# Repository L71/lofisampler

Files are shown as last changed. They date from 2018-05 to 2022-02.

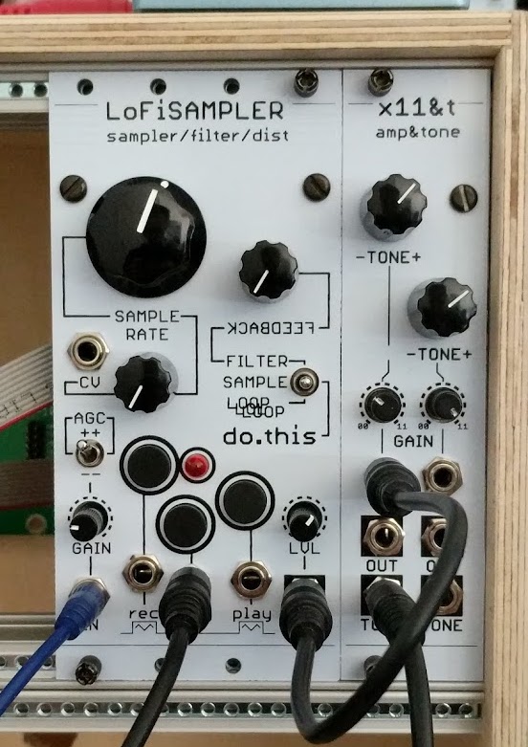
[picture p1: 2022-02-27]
lofisampler_tonecontrol.jpeg

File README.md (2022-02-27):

LoFi sampler / filter / dist module
===================================

This is a Eurorack module built upon the circuits described here: 

http://www.bastl-instruments.com/instruments/omsynth/omsynthvideo3/
http://www.bastl-instruments.com/instruments/omsynth/omsynthvideo3/lo-fi-vcf/

The added stuff here is Eurorack power supply circuits, an output amplifier and
some circuitry to get correct polarity on the sample rate/filter bandwidth control voltage.

It does sample and play stuff back but it's _really_ lofi as a sampler, lots of clicks at
start and stop of playback. It works better as a lofi filter or dist.

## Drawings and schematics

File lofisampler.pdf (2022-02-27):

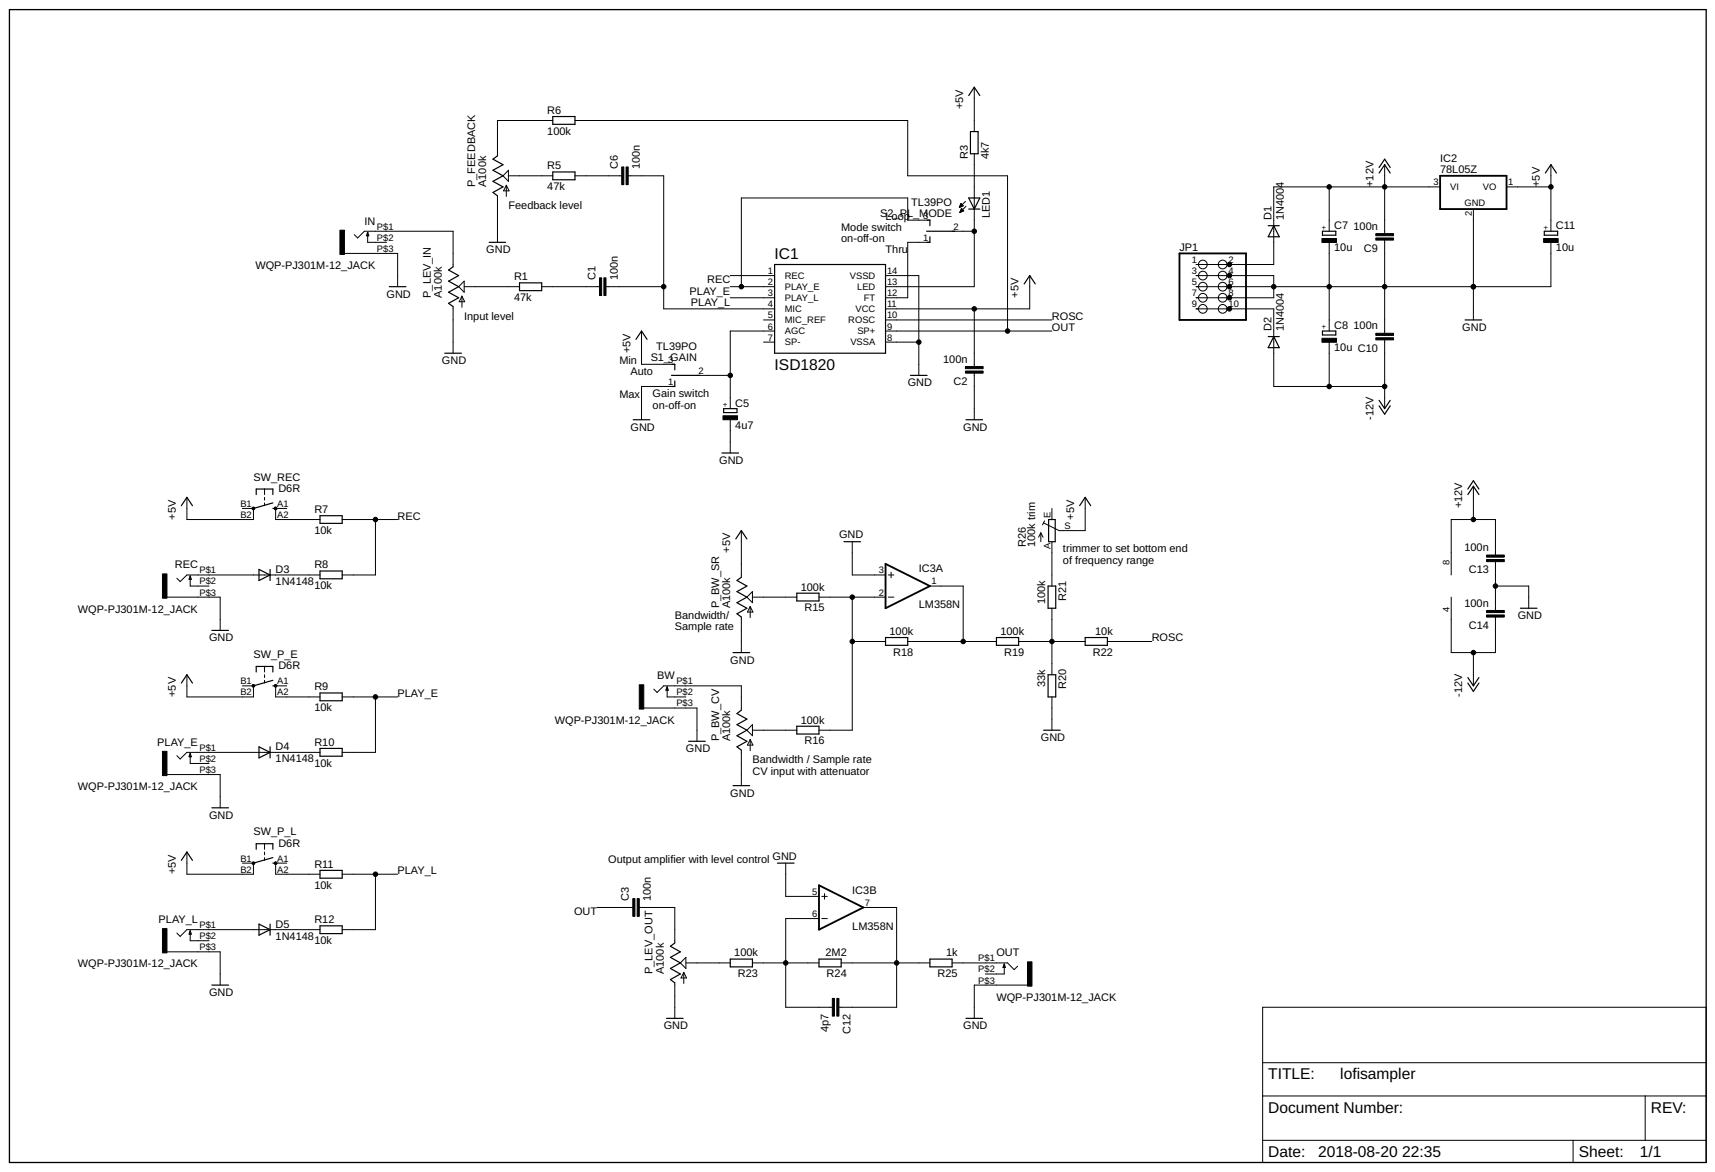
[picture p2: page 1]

trimmer to set bottom end
of frequency range

Bandwidth / Sample rate CV input with attenuator Output amplifier with level control

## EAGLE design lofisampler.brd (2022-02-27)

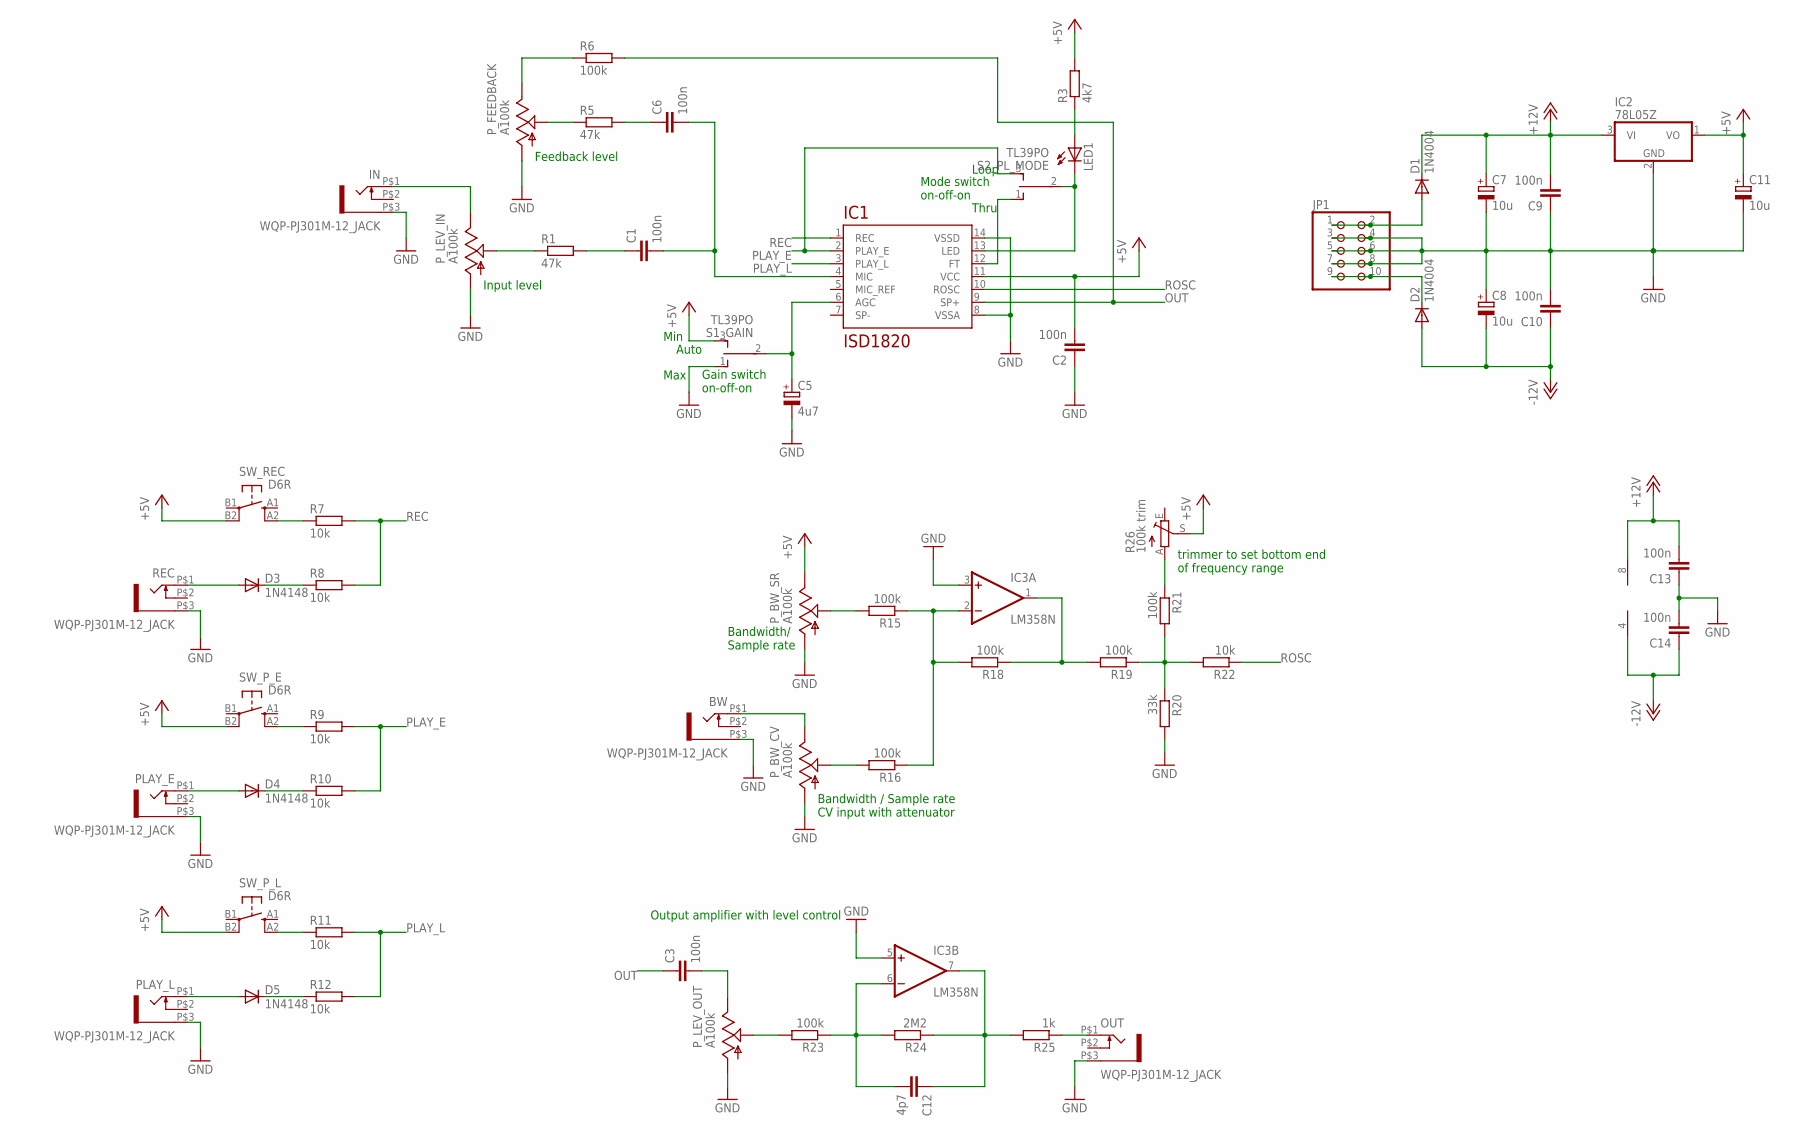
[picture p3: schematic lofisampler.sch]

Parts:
BW: WQP-PJ301M-12_JACK
C1, C3, C6: 100n; C050-025X075
C2, C9, C10, C13, C14: 100n; C025-025X050
C5: 4u7; E2,5-5
C7, C8, C11: 10u; E2,5-5
C12: 4p7; C025-025X050
D1, D2: 1N4004; DO41-10
D3, D4, D5: 1N4148; DO35-7
IC1: ISD1820; DIL14
IC2: 78L05Z; TO92
IC3: LM358N; DIL08
IN: WQP-PJ301M-12_JACK
JP1: PINHD-2X5; 2X05
LED1: LED5MM
OUT: WQP-PJ301M-12_JACK
PLAY_E: WQP-PJ301M-12_JACK
PLAY_L: WQP-PJ301M-12_JACK
P_BW_CV: A100k; ALPS_POT_VERTICAL
P_BW_SR: A100k; ALPS_POT_VERTICAL
P_FEEDBACK: A100k; ALPS_POT_VERTICAL
P_LEV_IN: A100k; ALPS_POT_VERTICAL
P_LEV_OUT: A100k; ALPS_POT_VERTICAL
R1, R5: 47k; 0207/2V
R3: 4k7; 0207/2V
R6, R15, R16, R18, R19, R21, R23: 100k; 0207/2V
R7, R8, R9, R10, R11, R12, R22: 10k; 0207/2V
R20: 33k; 0207/2V
R24: 2M2; 0207/2V
R25: 1k; 0207/2V
R26: 100k trim; B25P
REC: WQP-PJ301M-12_JACK
S1_GAIN, S2_PL_MODE: TL39PO; TL3XPO
SW_P_E: D6R
SW_P_L: D6R
SW_REC: D6R

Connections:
+5V: C2.2, C11.+, IC1.11 (VCC), IC2.1 (VO), P_BW_SR.P$1 (E), R3.2, R26.S, S1_GAIN.3 (S), SW_P_E.B2 (P1), SW_P_L.B2 (P1), SW_REC.B2 (P1)
+12V: C7.+, C9.2, C13.2, D1.C, IC2.3 (VI), IC3.8 (V+)
-12V: C8.-, C10.1, C14.1, D2.A, IC3.4 (V-)
GND: BW.P$3 (1), C2.1, C5.-, C7.-, C8.+, C9.1, C10.2, C11.-, C13.1, C14.2, IC1.8 (VSSA), IC1.14 (VSSD), IC2.2 (GND), IC3.3 (+IN), IC3.5 (+IN), IN.P$3 (1), JP1.3, JP1.4, JP1.5, JP1.6, JP1.7, JP1.8, OUT.P$3 (1), PLAY_E.P$3 (1), PLAY_L.P$3 (1), P_BW_CV.P$3 (A), P_BW_SR.P$3 (A), P_FEEDBACK.P$3 (A), P_LEV_IN.P$3 (A), P_LEV_OUT.P$3 (A), R20.2, REC.P$3 (1), S1_GAIN.1 (O)
unnamed: IN.P$1 (2), P_LEV_IN.P$1 (E)
unnamed: P_LEV_IN.P$2 (S), R1.1
unnamed: C1.1, R1.2
unnamed: C1.2, C6.2, IC1.4 (MIC)
unnamed: LED1.A, R3.1
unnamed: IC1.13 (LED), LED1.K (C), S2_PL_MODE.2
unnamed: IC1.12 (FT), S2_PL_MODE.1 (O)
unnamed: P_FEEDBACK.P$1 (E), R6.1
unnamed: D1.A, JP1.1, JP1.2
unnamed: P_FEEDBACK.P$2 (S), R5.1
unnamed: C5.+, IC1.6 (AGC), S1_GAIN.2
unnamed: C6.1, R5.2
unnamed: D2.C, JP1.9, JP1.10
unnamed: R21.1, R26.A
unnamed: C3.2, P_LEV_OUT.P$1 (E)
unnamed: P_LEV_OUT.P$2 (S), R23.2
unnamed: C12.2, IC3.6 (-IN), R23.1, R24.2
unnamed: D3.A, REC.P$1 (2)
unnamed: D3.C, R8.1
unnamed: P_BW_SR.P$2 (S), R15.2
unnamed: R7.1, SW_REC.A2 (S1)
unnamed: P_BW_CV.P$2 (S), R16.2
unnamed: D4.A, PLAY_E.P$1 (2)
unnamed: D4.C, R10.1
unnamed: IC3.2 (-IN), R15.1, R16.1, R18.2
unnamed: R9.1, SW_P_E.A2 (S1)
unnamed: D5.A, PLAY_L.P$1 (2)
unnamed: D5.C, R12.1
unnamed: C12.1, IC3.7 (OUT), R24.1, R25.2
unnamed: R11.1, SW_P_L.A2 (S1)
unnamed: IC3.1 (OUT), R18.1, R19.2
unnamed: BW.P$1 (2), P_BW_CV.P$1 (E)
unnamed: R19.1, R20.1, R21.2, R22.2
unnamed: OUT.P$1 (2), R25.1
OUT: C3.1, IC1.9 (SP+), R6.2
PLAY_E: IC1.2 (PLAY_E), R9.2, R10.2, S2_PL_MODE.3 (S)
PLAY_L: IC1.3 (PLAY_L), R11.2, R12.2
REC: IC1.1 (REC), R7.2, R8.2
ROSC: IC1.10 (ROSC), R22.1

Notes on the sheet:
Loop
Thru
Max
Min
Auto
Input level
Feedback level
Gain switch on-off-on
Mode switch on-off-on
Bandwidth/ Sample rate
Bandwidth / Sample rate CV input with attenuator
Output amplifier with level control
trimmer to set bottom end of frequency range

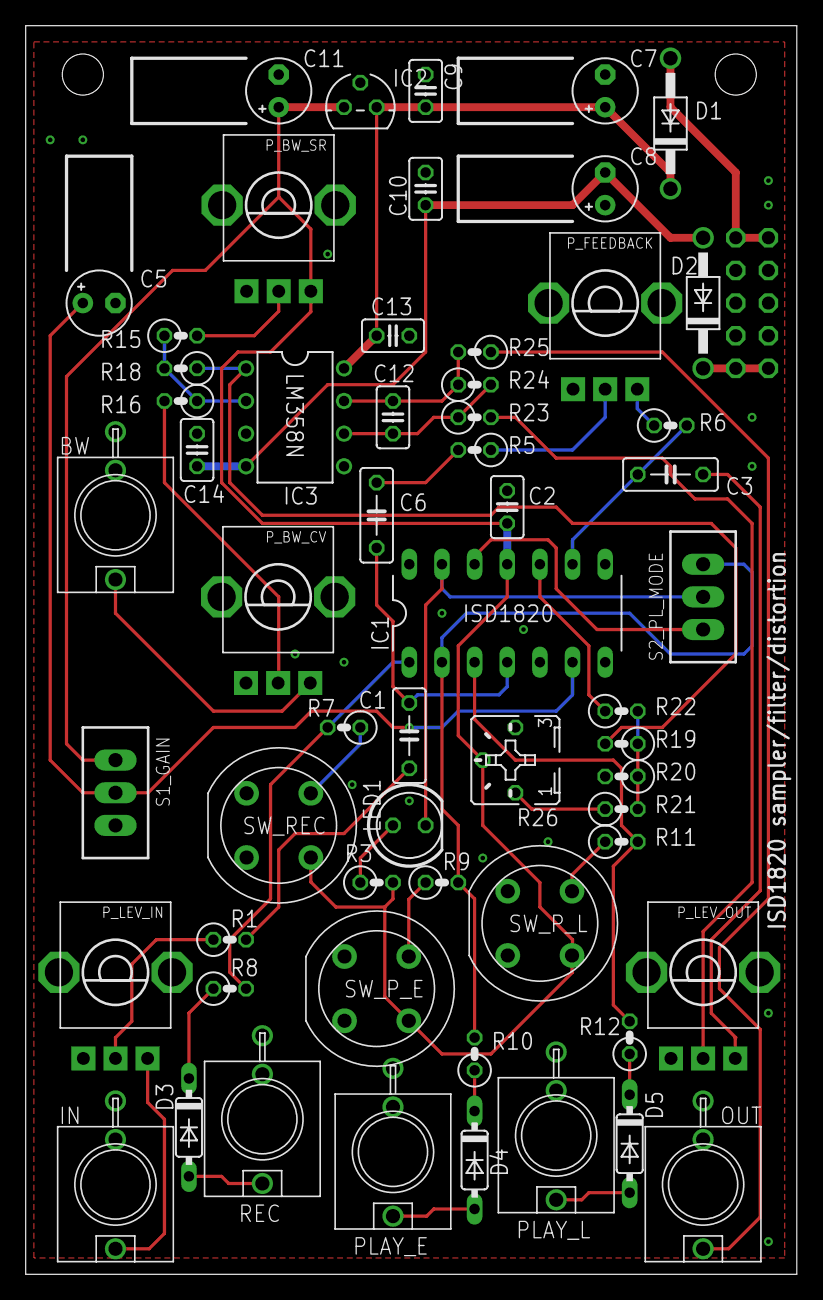
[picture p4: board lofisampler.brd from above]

Board: 2 copper layers, 60.0 x 97.1 mm, 60 parts (1 on the bottom side), 43 nets.

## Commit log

2018-05-30 Initial commit. First ordered prototype version.
    [lofisampler-1.0-PCB-panel.brd, lofisampler.brd, lofisampler.sch]
2018-06-07 Changed current limit resistors for the push buttons to 10k. Using 47k seems to deliver too small a current sometimes (some chips do not trigger on this).
    [lofisampler.brd, lofisampler.sch]
2022-02-27 latest updates
    [lofisampler.brd, lofisampler.sch]

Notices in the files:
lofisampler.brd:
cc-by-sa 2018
